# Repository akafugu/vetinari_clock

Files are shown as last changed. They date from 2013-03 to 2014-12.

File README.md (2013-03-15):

VETINARI CLOCK
==============

Introduction
---

A clock that ticks randomly, but still keeps accurate time!

The idea comes from the Discworld series of books by Sir Terry Pratchett.
Lord Havelock Vetinari is a recurring character in the book series, and he
is in possesion of a very strange clock.

From wikipedia:

"Lord Vetinari also has a strange clock in his waiting-room. While it does keep completely accurate time overall, it sometimes ticks and tocks out of sync (example: "tick, tock... ticktocktick, tock...") and occasionally misses a tick or tock altogether, which has the net effect of turning one's brain "into a sort of porridge". (Feet of Clay, Going Postal). In Feet of Clay Vimes observes that it must have cost him quite a lot of money."

Design files
---

Cad files for Eagle (version 6 or newer) are available in this repository.

Full kits with all required components are also available directly from
[Akafugu Corporation](http://akafugu.jp/posts/products/vetinariclock)

Source code
---

The firmware is a straight port of Simon Inns' original version for PIC12F683
to Attiny25.

The microcontroller is run from a 32kHz crystal, with Timer 1 set up to give
4 overflows each second.

From the original explanation on the webpage:

The firmware has a 'random' sequence of pulses which over 32 seconds moves the
second hand 32 times. This sequence is long enough to give the appearance of
randomness without unnecessarily consuming processor cycles. I chose 32 seconds
as it means the pattern is constantly offset from the 60 second rotation of the
minutes. The 'random' pattern is 128 steps (and is therefore checked 4 times a
second). This means the clock moves between 0-4 times within each actual second.
By moving more or less in each of the 32 seconds the clock looks random, however
the sequence always moves the clock exactly 32 seconds in the 128 steps.

Attribution
---

Original project and code for PIC PIC12F683 by Simon Inns:

http://www.waitingforfriday.com/index.php/Vetinari%27s_Clock

avr-gcc port for Attiny25 by Akafugu Corporation:

http://akafugu.jp/posts/products/vetinariclock

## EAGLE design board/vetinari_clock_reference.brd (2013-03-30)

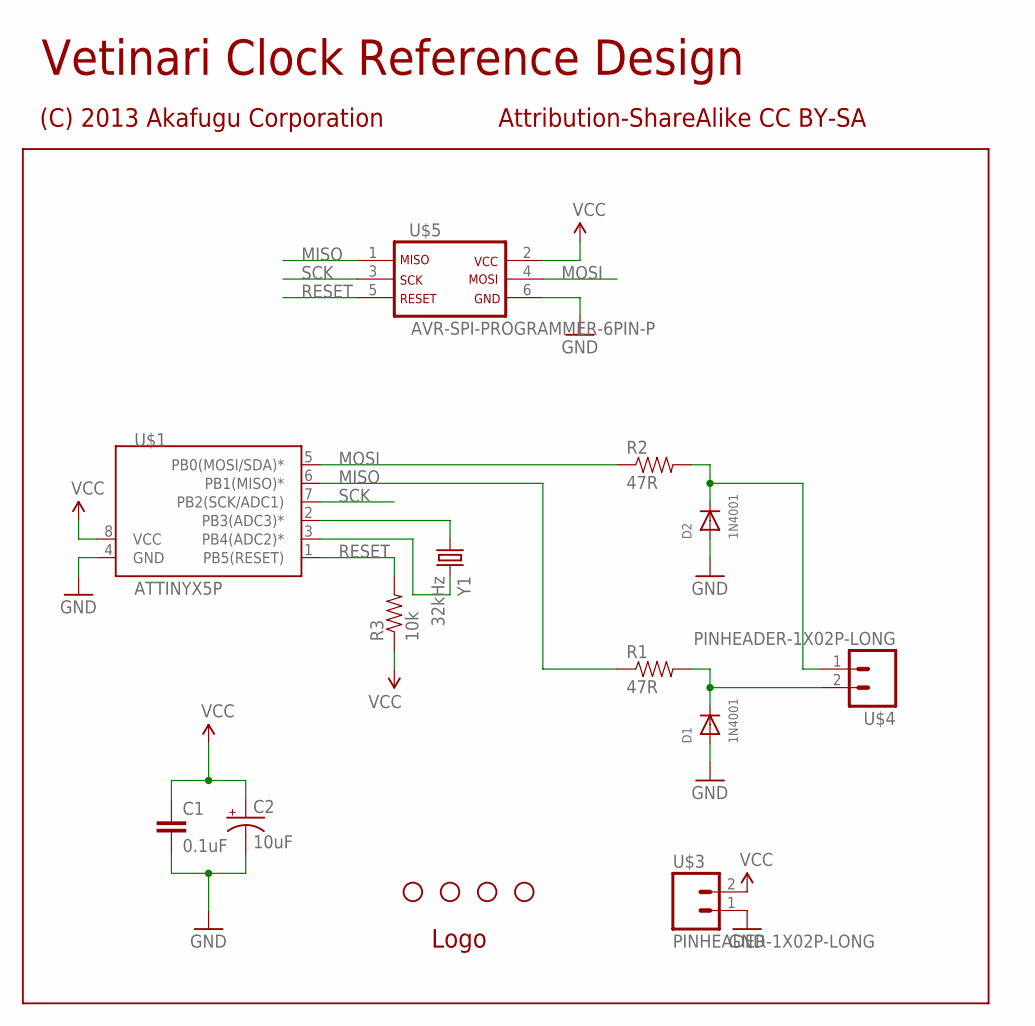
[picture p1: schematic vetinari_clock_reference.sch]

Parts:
C1: 0.1uF; CAP-PTH-2.54MM
C2: 10uF; CPOL-RADIAL-SLIM
D1, D2: 1N4001; DIODE-1N4001-BIGHOLES
JP1, JP2, JP3, JP4: STAND-OFF
R1, R2: 47R; 1/6W-RES-OUTLINE
R3: 10k; 1/6W-RES-OUTLINE
U$1: ATTINYX5P; DIL-8
U$3, U$4: PINHEADER-1X02P-LONG; 1X02-LONG
U$5: AVR-SPI-PROGRAMMER-6PIN-P; 2X03
U$6: OSHW-LOGO-OUTLINE
Y1: 32kHz; TC38H

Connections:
GND: C1.2, C2.2 (-), D1.A, D2.A, U$1.4 (GND), U$3.1, U$5.6
MISO: R1.1, U$1.6 (PB1(MISO)*), U$5.1
MOSI: R2.1, U$1.5 (PB0(MOSI/SDA)*), U$5.4
unnamed: D1.C, R1.2, U$4.2
unnamed: U$1.2 (PB3(ADC3)*), Y1.1
unnamed: U$1.3 (PB4(ADC2)*), Y1.2
unnamed: D2.C, R2.2, U$4.1
RESET: R3.2, U$1.1 (PB5(RESET)), U$5.5
SCK: U$1.7 (PB2(SCK/ADC1)), U$5.3
VCC: C1.1, C2.1 (+), R3.1, U$1.8 (VCC), U$3.2, U$5.2

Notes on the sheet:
Vetinari Clock Reference Design
(C) 2013 Akafugu Corporation
Attribution-ShareAlike CC BY-SA

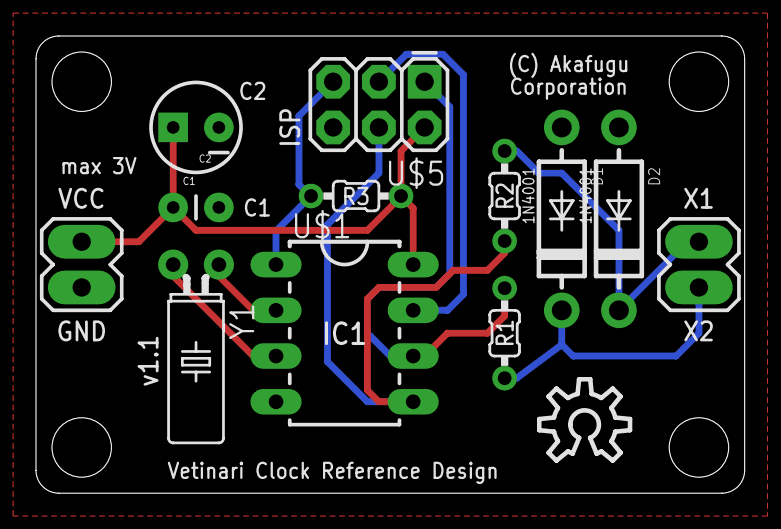
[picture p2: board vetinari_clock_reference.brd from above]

Board: 2 copper layers, 39.4 x 25.4 mm, 17 parts (0 on the bottom side), 10 nets.

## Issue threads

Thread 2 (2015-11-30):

Recommended power reduction changes

nsayer, 2015-11-30:
You should consider adding this:

#include <avr/power.h>

and then to the start of main():

ADCSRA = 0;
power_adc_disable();
power_usi_disable();
power_timer0_disable();

This will dramatically increase battery life.

You can also use

EMPTY_INTERRUPT(TIMER1_OVF);

for slightly shorter code if all the ISR does is a no-op.

You might also consider using timer 0 instead of timer 1, as it uses 80% less power (ATTinyx5 datasheet section 22.3).

perjg, 2015-12-09:
@nsayer Thanks for the suggestions, we'll look into adding them.

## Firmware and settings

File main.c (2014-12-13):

/*
 * Vetinari Clock
 * (C) 2011 Simon Inns
 *
 * avr-gcc port for Attiny25
 * (C) 2013 Akafugu Corporation
 *
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
 */

#include <avr/io.h>
#include <avr/interrupt.h>
#include <avr/sleep.h>
#include <util/delay.h>
#include <avr/pgmspace.h>

#include <stdbool.h>

#ifndef cbi
#define cbi(sfr, bit) (_SFR_BYTE(sfr) &= ~_BV(bit))
#endif
#ifndef sbi
#define sbi(sfr, bit) (_SFR_BYTE(sfr) |= _BV(bit))
#endif

#define _NOP() do { __asm__ __volatile__ ("nop"); } while (0) 

#define X1_BIT PB0
#define X2_BIT PB1

// Define the amount of time (in mS) that the coil should
// be energised for a 'tick'.  This should be as low as 
// possible but varies between clock modules...
#define ENERGISE_TIME 60

// 128 timing values for 32 seconds
// (4 possible movements per second * 32 seconds = 128)
const uint8_t timingSequence[128] PROGMEM = {
  1, 1, 0, 0, 0, 0, 1, 0, 0, 0, 0, 0, 0, 0, 1, 1, 0, 0,
  0, 0, 1, 0, 1, 0, 0, 0, 0, 1, 0, 0, 0, 0, 0, 0, 1, 1,
  0, 0, 0, 1, 0, 0, 1, 0, 0, 0, 1, 0, 0, 1, 0, 1, 0, 0,
  1, 0, 0, 0, 0, 0, 0, 1, 0, 1, 0, 0, 0, 0, 0, 0, 0, 0,
  1, 0, 0, 0, 0, 0, 0, 0, 1, 1, 0, 0, 0, 0, 0, 0, 0, 0,
  0, 0, 1, 0, 1, 0, 1, 0, 1, 1, 0, 0, 0, 0, 0, 0, 1, 0,
  0, 0, 0, 0, 0, 0, 1, 0, 0, 0, 0, 1, 1, 0, 0, 0, 0, 0,
  1, 1
  };
  
// The randomisation amount adds a delay before moving the 
// seconds hand to ensure the movement is not always on the 
// quarter second boundary.  The extra delay is in units of
// 5 mS.
const uint8_t timingRandomisation[15] PROGMEM = {
  0, 6, 8, 2, 10, 3, 4, 1, 7, 9, 5, 3, 8, 5, 9
  };  

volatile uint8_t timingPosition = 0;
volatile uint8_t randomisationPosition = 0;

// Global for storing the currently required polarity
volatile uint8_t polarity = 0;

void tick(void)
{
  PORTB |= (1 << X1_BIT);
  PORTB &= ~(1 << X2_BIT);
}

void tock(void)
{
  PORTB |= (1 << X2_BIT);
  PORTB &= ~(1 << X1_BIT);
}

void reset(void)
{
  PORTB |= (1<< X1_BIT);
  PORTB |= (1<< X2_BIT);
}

// Send a pulse to the clock module
void pulseClock(void)
{
  if (polarity == 0) {
    tick();
    _delay_ms(ENERGISE_TIME);
    reset();
    polarity = 1;
  }
  else
  {
    tock();
    _delay_ms(ENERGISE_TIME);
    reset();
    polarity = 0;
  }   
} 

int main(void) {
  // Enable timer 1 with 32 prescaler.
  // This gives 1/4 second between each overflow
  // (32 * 256 / 32768 clocks = 1/4 second)
  sbi(TCCR1, CS12);
  sbi(TCCR1, CS11);
  sbi(TIMSK, TOIE1); 
  sei();
	
	DDRB = (1<<X1_BIT)|(1<< X2_BIT);
  reset();

	PORTB |= (1<<PB2); // Turn on pull-up on unused pin
	
  set_sleep_mode(SLEEP_MODE_IDLE);

  while(1)
  {
    if (pgm_read_byte(&timingSequence[timingPosition]) == 1)
    {
      // Wait for the randomisation amount
      for (unsigned char delay = 0; delay < pgm_read_byte(&timingRandomisation[randomisationPosition]); delay++)
        _delay_ms(5);
        
      randomisationPosition++;
      if (randomisationPosition == 15) randomisationPosition = 0; 
        
      pulseClock();
    } 
    
    timingPosition++;
    if (timingPosition == 128) timingPosition = 0;

    sleep_mode(); // system sleeps here
  } 
}

// Timer 1 interrupt (will wake system from idle sleep mode)
ISR(TIMER1_OVF_vect) {
  _NOP();
}

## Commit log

2013-03-30 Eagle reference design
    [vetinari_clock_reference.brd, vetinari_clock_reference.sch]
2013-04-05 Data space overflow fix
    [main.c]
2013-04-05 Fix for battery consumption. Cleanup
    [main.c]

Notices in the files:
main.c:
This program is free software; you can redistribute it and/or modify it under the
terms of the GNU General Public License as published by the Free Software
